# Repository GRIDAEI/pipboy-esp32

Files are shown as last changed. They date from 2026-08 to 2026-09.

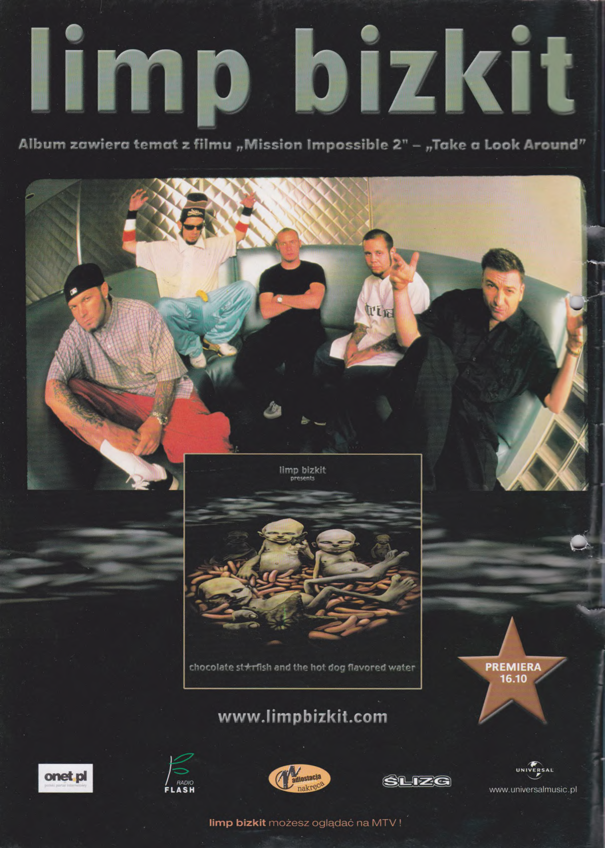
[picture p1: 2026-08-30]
FABRYKA-IMG-DO-ESP32/Klan Nr 15 (2000)_0002.png

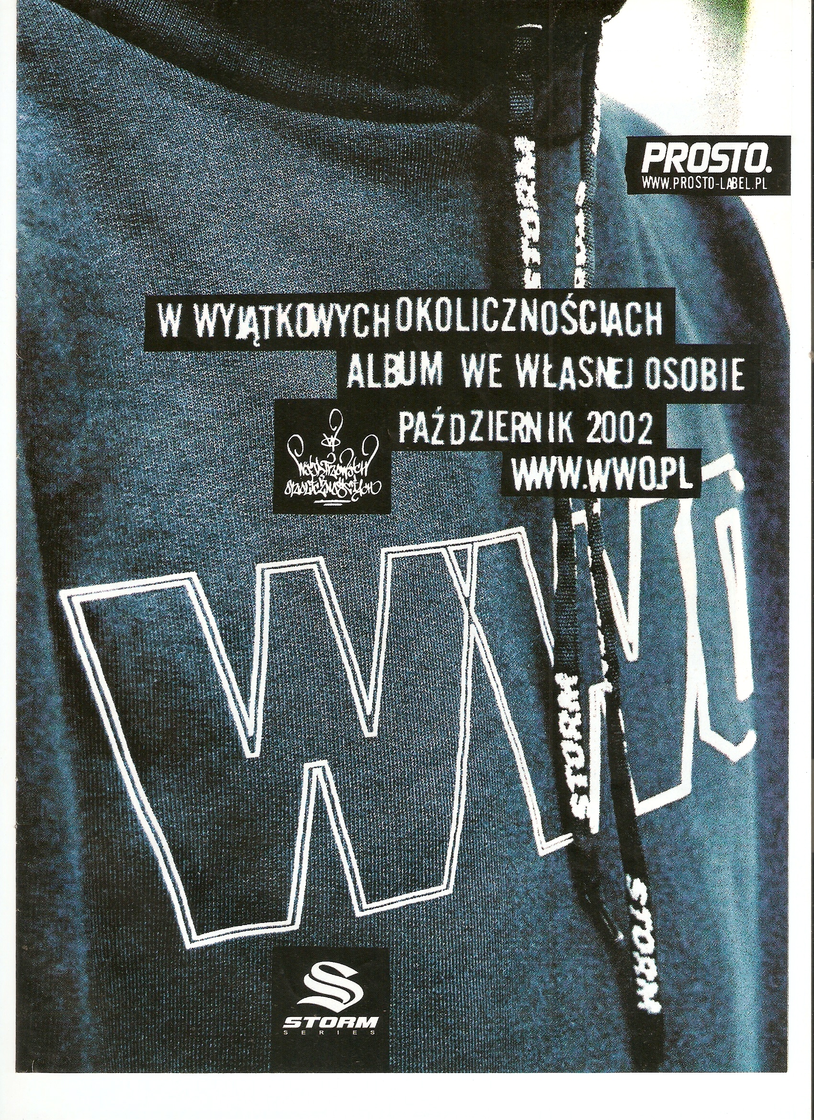
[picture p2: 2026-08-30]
FABRYKA-IMG-DO-ESP32/43xKLANxNr27x2002.jpg

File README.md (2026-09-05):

# Pip-Boy 3000 - ESP32-S3 Replica OS ☢️






Projekt ma na celu jak najdokładniejsze odtworzenie kultowego urządzenia z serii gier Fallout.
**Pip-Boy 3000**, znany głównie z _Fallout 3_ oraz _Fallout: New Vegas_, zyskuje tu nowe życie dzięki mikrokontrolerowi ESP32-S3. Projekt łączy oprogramowanie (UI/UX) z fizycznym sprzętem, tworząc realistyczny rekwizyt.

## Funkcje

- **Płynny Interfejs i Animacje**: Wykorzystanie biblioteki [LovyanGFX](https://github.com/lovyan03/LovyanGFX) zapewnia wysoką wydajność renderowania na ekranie.
- **System Audio I2S**: Autentyczne efekty dźwiękowe interfejsu (kliknięcia, przejścia w menu) odtwarzane przez `ESP8266Audio` i miksowane w czasie rzeczywistym.
- **Pełna Nawigacja**: Enkoder obrotowy, przełącznik obrotowy oraz fizyczne przyciski idealnie zmapowane, co pozwala na nawigację po zakładkach Statystyk, Ekwipunku i Danych, dokładnie tak jak w grze.
- **Ładowanie Obrazów do PSRAM**: Wysokiej rozdzielczości sprite'y (mapy, przedmioty) ładowane dynamicznie do 8MB pamięci PSRAM w celu oszczędzania pamięci RAM.
- **Zegar Czasu Rzeczywistego (RTC)**: Zegar systemowy z możliwością dostosowania i zapisem w pamięci NVS, odporny na restarty.
- **Motywy Kolorystyczne**: Obsługa różnych kolorów interfejsu (Klasyczny Zielony, Bursztynowy, Quantum Blue).
- **Oszczędzanie Energii**: Inteligentne wykrywanie bezczynności obniża taktowanie procesora do 80MHz, by oszczędzać baterię podczas długich wędrówek po Pustkowiach.

## Gotowe Płytki PCB

W projekcie zawarto pliki produkcyjne dla autorskich płytek drukowanych (PCB). Dostępne są **2 wersje** płytki, z czego **najnowsza rewizja v3.0 jest wysoce zalecana** ze względu na znaczne poprawki stabilności układu.

## Dokumentacja Projektu

Szczegółowe informacje techniczne oraz instrukcje zostały wydzielone do osobnych plików, aby ułatwić nawigację po repozytorium:

- **[Sprzęt i Elektronika (Hardware)](docs/HARDWARE.md)** – schemat układu, kompletna lista komponentów (BOM), tabela podłączeń pinów oraz informacje o zastosowanych modułach (wibracje, DAC).
- **[Architektura Oprogramowania (Software)](docs/SOFTWARE.md)** – objaśnienie działania interfejsu wizualnego (LovyanGFX), buforowanie tekstur w PSRAM, obsługa przerwań enkodera oraz zarządzanie dźwiękiem z LittleFS.
- **[Instrukcja Budowy (Build Guide)](docs/BUILD_GUIDE.md)** – przewodnik krok po kroku, jak skompilować projekt, skonfigurować środowisko PlatformIO i wgrać wymagany obraz pamięci Flash.

## 📁 Struktura Projektu

- `/src/screens/` - Logika odpowiedzialna za poszczególne zakładki interfejsu (Status, S.P.E.C.I.A.L, Ekwipunek, Mapy).
- `/src/modules/` - Sterowniki modułów takich jak Audio (I2S), Enkoder i obsługa karty SD.
- `/src/imgs/` - Tekstury, sprite'y i tablice z grafikami przygotowanymi do użycia.
- `/docs/` - Rozszerzona dokumentacja techniczna projektu.
- `main.cpp` - Główna pętla programu, sekwencja startowa (Boot OS) i dystrybucja wejść.

## Licencja

To jest projekt fanowski. _Pip-Boy_, _Vault Boy_ oraz _Fallout_ są zarejestrowanymi znakami towarowymi Bethesda Softworks LLC. Projekt został stworzony wyłącznie w celach edukacyjnych oraz hobbystycznych (cosplay).

---

_"Prepared for the Future"_ -- Vault-Tec Corporation

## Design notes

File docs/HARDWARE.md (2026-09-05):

# Sprzęt i Elektronika (Hardware)

Ten dokument opisuje warstwę sprzętową projektu Pip-Boy 3000, w tym użyte komponenty, zasilanie oraz peryferia.

## Schemat i Główne Moduły

Projekt opiera się na mikrokontrolerze **ESP32-S3**, który zarządza wyświetlaczem SPI, dźwiękiem I2S oraz czytnikiem kart pamięci, a także zbiera sygnały wejściowe od użytkownika.

### 1. Mikrokontroler

Zastosowano płytkę ewaluacyjną **ESP32-S3-DEVKITC-1-N16R8**.

- **Dlaczego ta wersja?** Układ ESP32-S3 jest wyposażony w dodatkową pamięć **8MB PSRAM (Octal SPI)**, co jest absolutnie kluczowe do buforowania dużych tekstur o wysokiej rozdzielczości (takich jak mapy czy animacje Vault Boya) bez zapychania standardowej pamięci RAM (której jest tylko 512KB).

### 2. Wyświetlacz TFT

Ekran komunikuje się z mikrokontrolerem po szybkiej magistrali SPI (piny `TFT_SCK`, `TFT_SDI`, `TFT_DC`, `TFT_CS`, `TFT_RESET`).

### 3. System Audio

Dźwięk generowany jest w pełni cyfrowo z wykorzystaniem protokołu I2S.

- **DAC:** Zewnętrzny moduł przetwornika (np. MAX98357A).
- Sygnały I2S: Zegar kanałów (`LRCLK`), Zegar bitowy (`BCLK`), oraz linia danych (`DIN`).

### 4. Sprzężenie zwrotne (Haptyka)

Aby symulować działanie "prawdziwego" urządzenia, zastosowano 2 silniczki wibracyjne (`Vibr1`, `Vibr2`).

- Są one sterowane poprzez **N-kanałowe tranzystory MOSFET** (Q2, Q3) działające jako klucze.
- Dołożono diody Schottky'ego (D1, D2) podłączone zaporowo, które pełnią funkcję tzw. _flyback diode_ – chronią porty mikrokontrolera przed przepięciami (skokami napięcia) powstającymi przy wyłączaniu cewek silników.

### 5. Pamięć Masowa

Płyta uwzględnia zewnętrzny moduł karty **Micro SD**, który służy jako dodatkowy magazyn danych na ciężkie pliki multimedialne.

---

## 🖨️ Projekty Płytek Drukowanych (PCB)

W głównym drzewie repozytorium znajdziesz gotowe projekty płytek drukowanych, które pozwalają złożyć system w profesjonalny, kompaktowy sposób bez plątaniny kabli (co ułatwia montaż w obudowie Pip-Boya).

Obecnie udostępniamy dwie wersje projektu PCB:

- **Wersja starsza**: Pierwotna koncepcja układu.
- **Wersja v3.0 (ZALECANA)**: Najnowsza rewizja płytki. Posiada kluczowe poprawki dotyczące stabilności układu, lepsze oddzielenie sekcji zasilania od części logicznej oraz zoptymalizowane prowadzenie ścieżek układu audio I2S (niwelacja szumów). Zdecydowanie polecamy produkcję i lutowanie **wersji v3.0**.

---

## 📋 Lista Komponentów (BOM)

Poniżej znajduje się zestawienie części potrzebnych do zbudowania elektroniki.

| Komponent | Model / Specyfikacja | Rola w systemie | Gdzie kupić (Link) |
| :--- | :--- | :--- | :--- |
| **Mikrokontroler** | ESP32-S3-DEVKITC-1-N16R8 | "Mózg" operacji, renderowanie UI, obsługa PSRAM | [Link](https://kamami.pl/esp32/1197037-esp32-s3-microcontroller-2-4ghz-wi-fi-development-board-240mhz-dual-core-processor-esp32-s3-wroom-5906623499045.html) |
| **Wyświetlacz** | [TFT SPI 4.0' ST7796] | Prezentacja interfejsu tft | [Link](https://pl.aliexpress.com/item/1005005787550807.html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) |
| **Przetwornik Audio** | MAX98357A | Odtwarzanie kliknięć i dźwięków UI po I2S | [Link](https://www.gotronik.pl/modul-wzmacniacza-audio-i2s-3w-klasa-d-dacmax98357-p-13866.html) |
| **Głośnik** | Głośnik 1W 8Ohm | Emisja dźwięku | [Link](https://botland.com.pl/glosniki-analogowe/26596-glosnik-1w-8ohm-30mm-sparkfun-com-27247-5904422387907.html) |
| **Enkoder obrotowy** | EC10E1220503 | Nawigacja góra/dół | [Link](https://www.tme.eu/pl/details/ec10e1220503/enkodery-inkrementalne/alps/) |
| **Przyciski funkcyjne** | [Uzupełnij np. Tact Switch 12x12mm]  | Zmiana zakładek (Stats, Items, Data) | [Uzupełnij] |
| **Silniki Wibracyjne** | [Uzupełnij np. płaskie silniki coin] | Haptyczne wibracje zwrotne | [Uzupełnij](Link) |
| **Tranzystory MOSFET** | [Uzupełnij np. 2N7002, logic-level]  | Włączanie zasilania silniczków (3.3V) z GPIO ESP32 | [Uzupełnij] |
| **Diody Zabezpieczające** | SS24 | Zabezpieczenie przed przepięciami z silników (flyback) | [Uzupełnij] |
| **Rezystory** | [Uzupełnij, np. 10kOhm pull-down] | Stabilizacja stanów na bramkach MOSFETów i SPI | [Uzupełnij] |
|  |

## 🔌 Tabela Połączeń (Pinout)

_Zostawiam to miejsce na szczegółową rozpiskę pinów. Ułatwia to testowanie na płytce stykowej._

| ESP32-S3 Pin | Komponent docelowy | Opis Sygnału |
| :--- | :--- | :--- |
| [Uzupełnij np. GPIO15] | `TFT_CS` | SPI Chip Select dla ekranu |
| ... | ... | ... |

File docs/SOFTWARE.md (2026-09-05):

# 💻 Architektura Oprogramowania (Software)

Projekt jest pisany w **C++** i kompilowany przy użyciu środowiska **PlatformIO** w frameworku Arduino dla ESP32.

Poniżej znajduje się omówienie kluczowych modułów programistycznych i decyzji architektonicznych.

## 🖼️ Interfejs Graficzny i Wyświetlacz (UI)

Zamiast standardowej i wolnej biblioteki TFT_eSPI, silnik GUI opiera się o bibliotekę **[LovyanGFX](https://github.com/lovyan03/LovyanGFX)**.

- **Wydajność:** LovyanGFX pozwala na asynchroniczne transfery DMA (Direct Memory Access) po magistrali SPI. Dzięki temu mikrokontroler nie jest zablokowany podczas przerysowywania pełnoekranowych klatek.
- **Double Buffering (Opcjonalnie):** W celu wyeliminowania zjawiska "migotania" (tearing/flickering) podczas odświeżania zakładek w interfejsie.

### Zarządzanie Pamięcią (PSRAM)

Zwykły ESP32 posiada zbyt mało pamięci RAM (ok. 520 KB), by pomieścić nieskompresowane mapy bitowe w 16-bitowym kolorze (np. 320x480).

- Rozwiązaniem jest wykorzystanie wariantu ESP32-S3 posiadającego **8MB zewnętrznej pamięci PSRAM**.
- Tekstury (jak grafiki Pip-Boya, mapy Pustkowi, ikony ekwipunku) zapisane są w pamięci flash. Podczas pracy programu, odpowiednie tekstury są wgrywane bezpośrednio na bieżąco (lub buforowane z wyprzedzeniem) do PSRAM przy użyciu `ps_malloc()`.
- Zapewnia to błyskawiczny dostęp do grafik podczas szybkiego przełączania między zakładkami.

## 🔊 System Audio (I2S)

Pip-Boy to nie tylko grafika, ale i kultowe dźwięki kliknięć i radiacji.

1.  Dźwięki (w formacie `.wav` lub `.mp3`) przechowywane są we wbudowanej pamięci Flash przy użyciu systemu plików **LittleFS** lub na zewnętrznej karcie pamięci Micro SD.
2.  Wykorzystywana jest biblioteka **ESP8266Audio**.
3.  Mikrokontroler strumieniuje dane dźwiękowe do zewnętrznego układu DAC poprzez sprzętową magistralę **I2S**. Użycie oddzielnego układu cyfrowo-analogowego minimalizuje zakłócenia i zniekształcenia dźwięku.
4.  Uruchomiono sprzętowe miksowanie kanałów, by w przyszłości nakładać efekty dźwiękowe UI (np. szum kliknięcia) na odtwarzane radio.

## 🎛️ Obsługa Wejść (Enkoder i Przyciski)

Do odczytu nawigacji wykorzystywany jest enkoder obrotowy i przyciski przednie (`FNTBTN`).

- **Przerwania (Interrupts):** Odczyt enkodera realizowany jest poprzez asynchroniczne przerwania sprzętowe (ISR), a nie poprzez ciągłe odpytywanie w pętli `loop()` (tzw. polling). Zapewnia to natychmiastową reakcję i to, że żaden "skok" obrotu nie zostanie zgubiony.
- **Debouncing:** Zaimplementowano programowy debouncing dla przycisków przednich oraz przełącznika pozycyjnego, by wyeliminować fałszywe podwójne wciśnięcia wywołane drganiem styków.

## ⚡ Struktura Główna

Kod źródłowy zorganizowany jest wokół głównych widoków:

- `/src/screens/` - Pliki definiujące rysowanie i logikę ekranów (Status, Inventory, Data, Map).
- `/src/modules/` - Klasy abstrakcyjne odpowiedzialne za podzespoły sprzętowe (Manager dźwięku, Manager wejść).

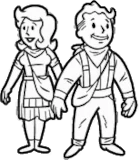
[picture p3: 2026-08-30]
FABRYKA-IMG-DO-ESP32/GoodspringsReputation.webp

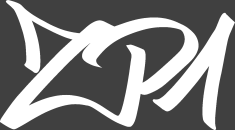
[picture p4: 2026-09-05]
FABRYKA-IMG-DO-ESP32/zp1.png

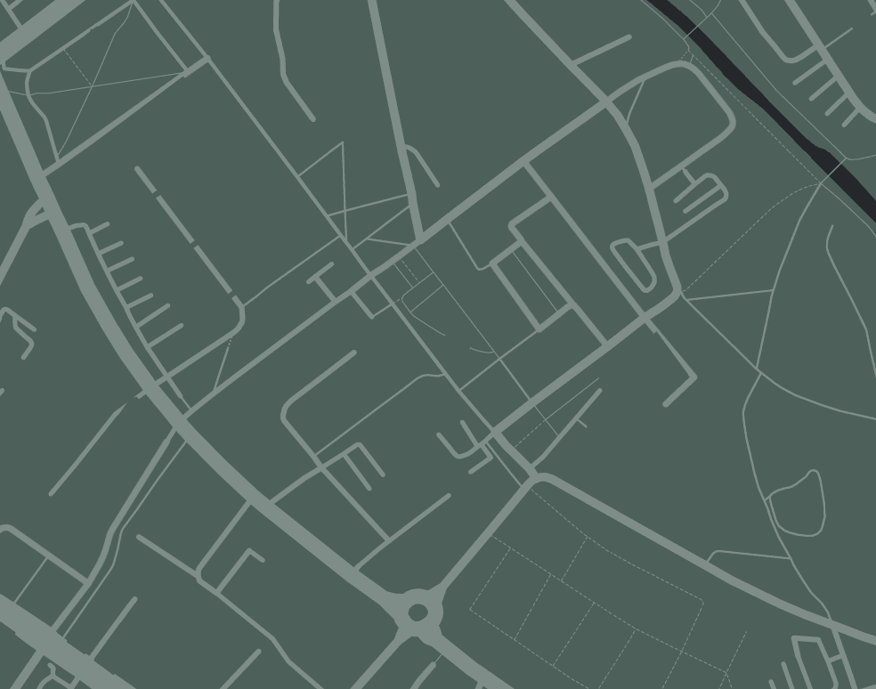
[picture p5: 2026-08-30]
FABRYKA-IMG-DO-ESP32/LocalMapSprite.png

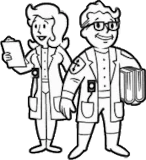
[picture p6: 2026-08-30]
FABRYKA-IMG-DO-ESP32/FollowersApocalypseReputation.webp

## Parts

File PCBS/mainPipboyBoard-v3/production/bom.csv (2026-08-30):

Designator | Footprint | Quantity | Value | LCSC Part #
C1 | C_Radial_D4.0mm_H5.0mm_P1.50mm | 1 | 100uF
C2 | 0805 | 1 | 100nF
C3 | C_Radial_D4.0mm_H5.0mm_P1.50mm | 1 | 470uF
C4 | 1206 | 1 | 100nF
C5 | 1206 | 1 | 10uf
D1, D2 | 1206 | 2 | D_Schottky
J1 | PinSocket_1x14_P2.54mm_Vertical | 1 | TFT
J11 | PinSocket_1x02_P2.54mm_Vertical | 1 | Vibr1
J12 | PinSocket_1x02_P2.54mm_Vertical | 1 | Vibr2
J13 | JST_ZH_B6B-ZR-SM4-TF_1x06-1MP_P1.50mm_Vertical | 1 | FNTBTNS
J2, J4 | PinSocket_1x01_P2.54mm_Vertical | 2 | Conn_01x01
J3 | 112JTDARR01 | 1 | Micro_SD_Card
J7 | PinSocket_1x03_P2.54mm_Vertical | 1 | PosSwitch
J8 | PinSocket_1x04_P2.54mm_Vertical | 1 | ROTENCODER
J9 | PinSocket_1x07_P2.54mm_Vertical | 1 | audio
Q2, Q3 | SOT-23 | 2 | AO3400A | C20917
R10, R4, R5, R6, R7, R8, R9 | 1206 | 7 | 10k
U1 | XCVR_ESP32-S3-DEVKITC-1-N8R2 | 1 | ESP32-S3-DEVKITC-1-N8R2

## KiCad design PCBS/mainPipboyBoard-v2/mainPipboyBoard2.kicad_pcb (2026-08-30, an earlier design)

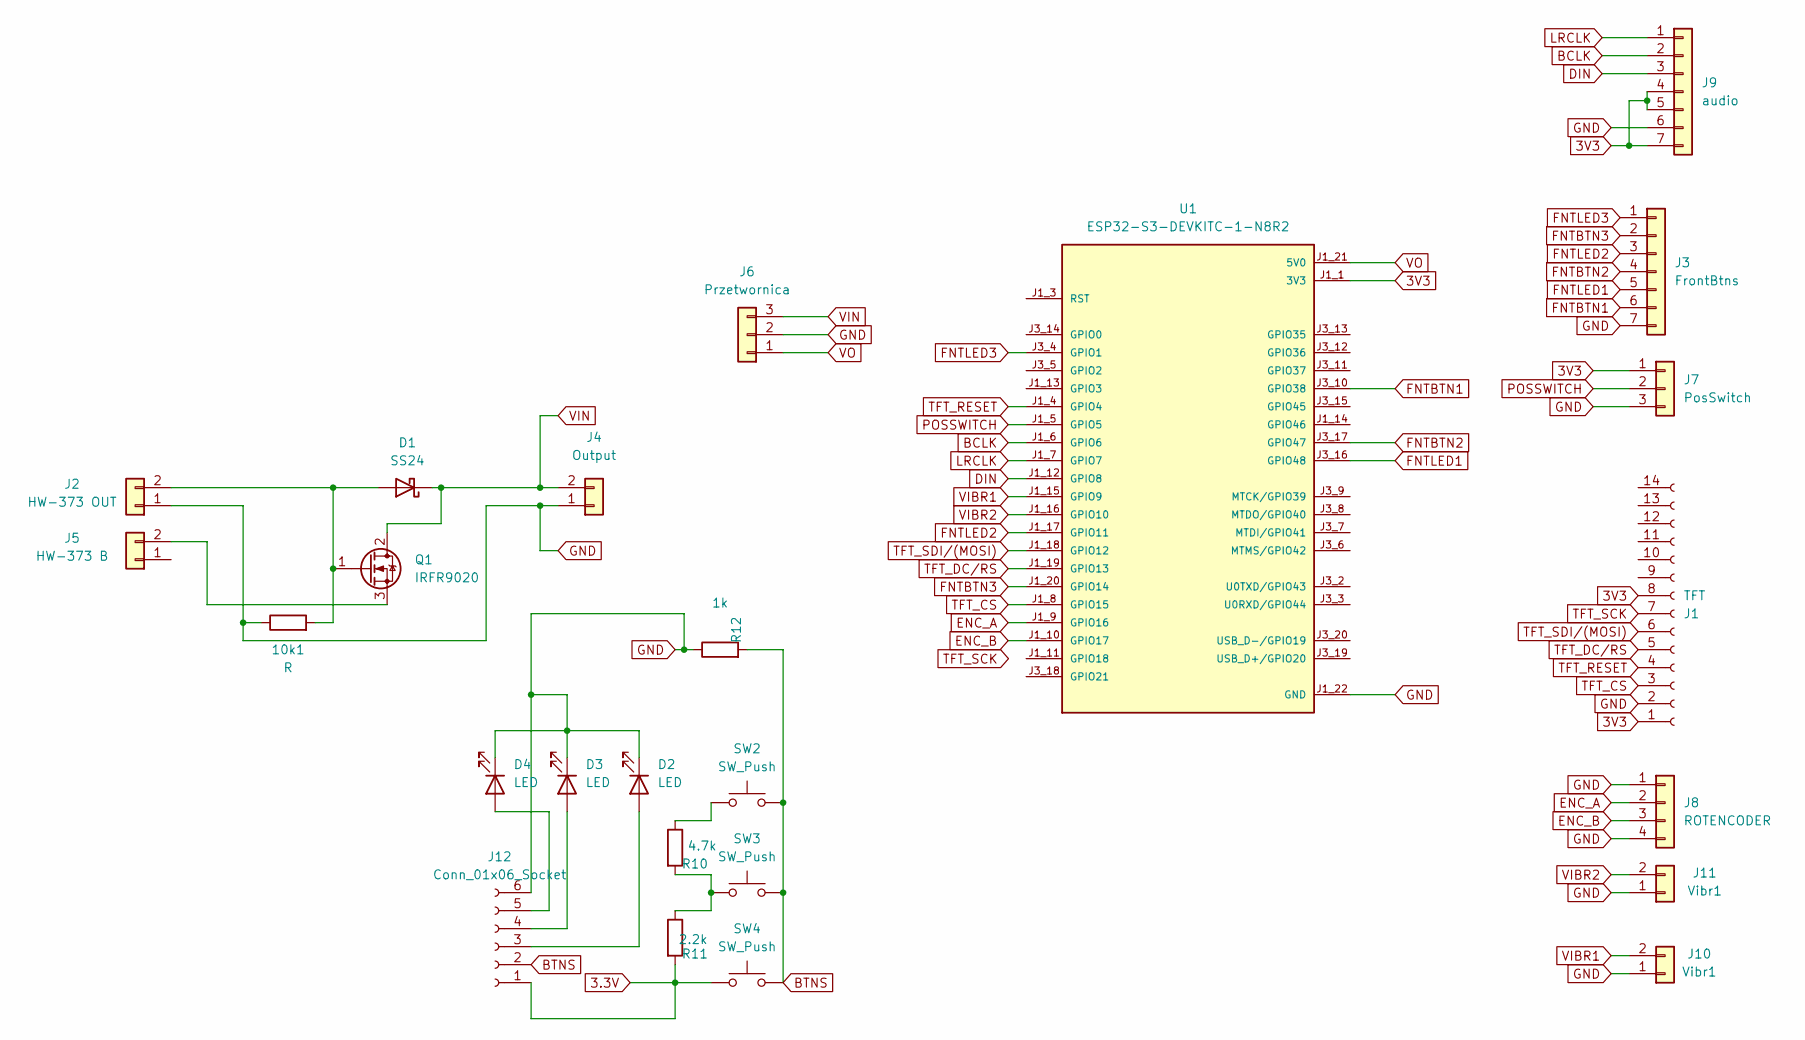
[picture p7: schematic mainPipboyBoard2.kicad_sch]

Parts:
10k1: R; R_1206_3216Metric_Pad1.30x1.75mm_HandSolder
D1: SS24; D_SMA
D2, D3, D4: LED; LED_1206_3216Metric_Pad1.42x1.75mm_HandSolder
J1: TFT; PinSocket_1x14_P2.54mm_Vertical
J2: HW-373 OUT; PinSocket_1x02_P2.54mm_Vertical
J3: FrontBtns; PinSocket_1x07_P2.54mm_Vertical
J4: Output; PinSocket_1x02_P2.54mm_Vertical
J5: HW-373 B; PinSocket_1x02_P2.54mm_Vertical
J6: Przetwornica; PinSocket_1x03_P2.54mm_Vertical
J7: PosSwitch; PinSocket_1x03_P2.54mm_Vertical
J8: ROTENCODER; PinSocket_1x04_P2.54mm_Vertical
J9: audio; PinSocket_1x07_P2.54mm_Vertical
J10, J11: Vibr1; PinSocket_1x02_P2.54mm_Vertical
J12: Conn_01x06_Socket; PinHeader_1x06_P2.54mm_Vertical_SMD_Pin1Right
Q1: IRFR9020; TO-252-2
R10: 4.7k; L_1206_3216Metric_Pad1.22x1.90mm_HandSolder
R11: 2.2k; L_1206_3216Metric_Pad1.22x1.90mm_HandSolder
R12: 1k; L_1206_3216Metric_Pad1.22x1.90mm_HandSolder
SW2, SW3, SW4: SW_Push; PTS810SJM250SMTRLFS
U1: ESP32-S3-DEVKITC-1-N8R2; XCVR_ESP32-S3-DEVKITC-1-N8R2; PARTREV V1

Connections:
3.3V: J12.1, R11.2, SW4.1
3V3: J1.1, J1.8, J7.1, J9.4, J9.5, J9.7, U1.J1_1 (3V3), U1.J1_2 (3V3)
BCLK: J9.2, U1.J1_6 (GPIO6)
BTNS: J12.2, R12.2, SW2.2, SW3.2, SW4.2
DIN: J9.3, U1.J1_12 (GPIO8)
ENC_A: J8.2, U1.J1_9 (GPIO16)
ENC_B: J8.3, U1.J1_10 (GPIO17)
FNTBTN1: J3.6, U1.J3_10 (GPIO38)
FNTBTN2: J3.4, U1.J3_17 (GPIO47)
FNTBTN3: J3.2, U1.J1_20 (GPIO14)
FNTLED1: J3.5, U1.J3_16 (GPIO48)
FNTLED2: J3.3, U1.J1_17 (GPIO11)
FNTLED3: J3.1, U1.J3_4 (GPIO1)
GND: 10k1.1, D2.1 (K), D3.1 (K), D4.1 (K), J1.2, J2.1, J3.7, J4.1, J6.2, J7.3, J8.1, J8.4, J9.6, J10.1, J11.1, J12.6, R12.1, U1.J1_22 (GND), U1.J3_1 (GND), U1.J3_21 (GND), U1.J3_22 (GND)
LRCLK: J9.1, U1.J1_7 (GPIO7)
unnamed: 10k1.2, D1.2 (A), J2.2, Q1.1 (G)
unnamed: D2.2 (A), J12.3
unnamed: D3.2 (A), J12.4
unnamed: D4.2 (A), J12.5
unnamed: J5.2 (Pin_2_2), Q1.3 (S)
unnamed: R10.1, SW2.1
unnamed: R10.2, R11.1, SW3.1
POSSWITCH: J7.2, U1.J1_5 (GPIO5)
TFT_CS: J1.3, U1.J1_8 (GPIO15)
TFT_DC/RS: J1.5, U1.J1_19 (GPIO13)
TFT_RESET: J1.4, U1.J1_4 (GPIO4)
TFT_SCK: J1.7
TFT_SDI/(MOSI): J1.6, U1.J1_18 (GPIO12)
VIBR1: J10.2, U1.J1_15 (GPIO9)
VIBR2: J11.2, U1.J1_16 (GPIO10)
VIN: D1.1 (K), J4.2, J6.3, Q1.2 (D)
VO: J6.1, U1.J1_21 (5V0)

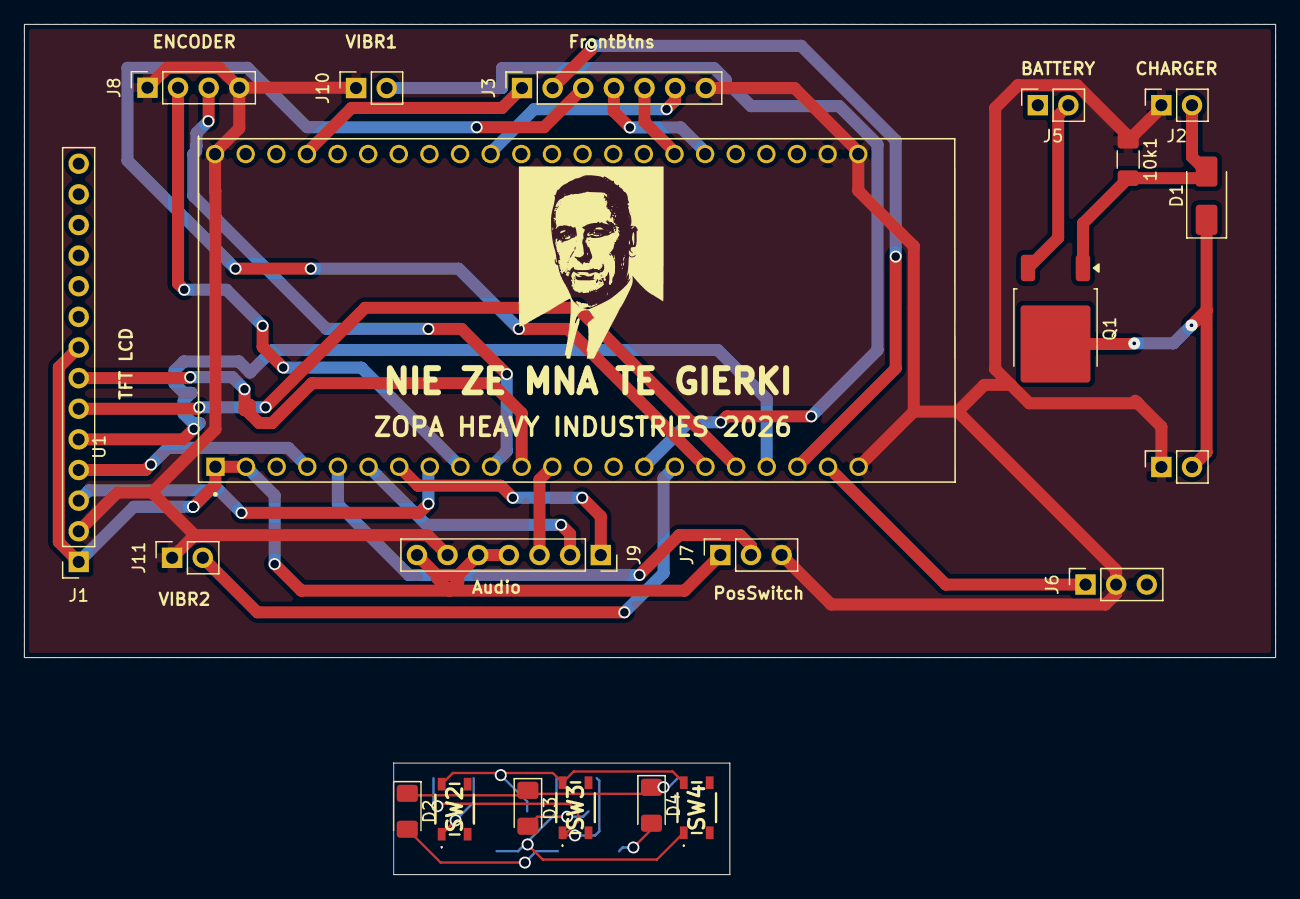
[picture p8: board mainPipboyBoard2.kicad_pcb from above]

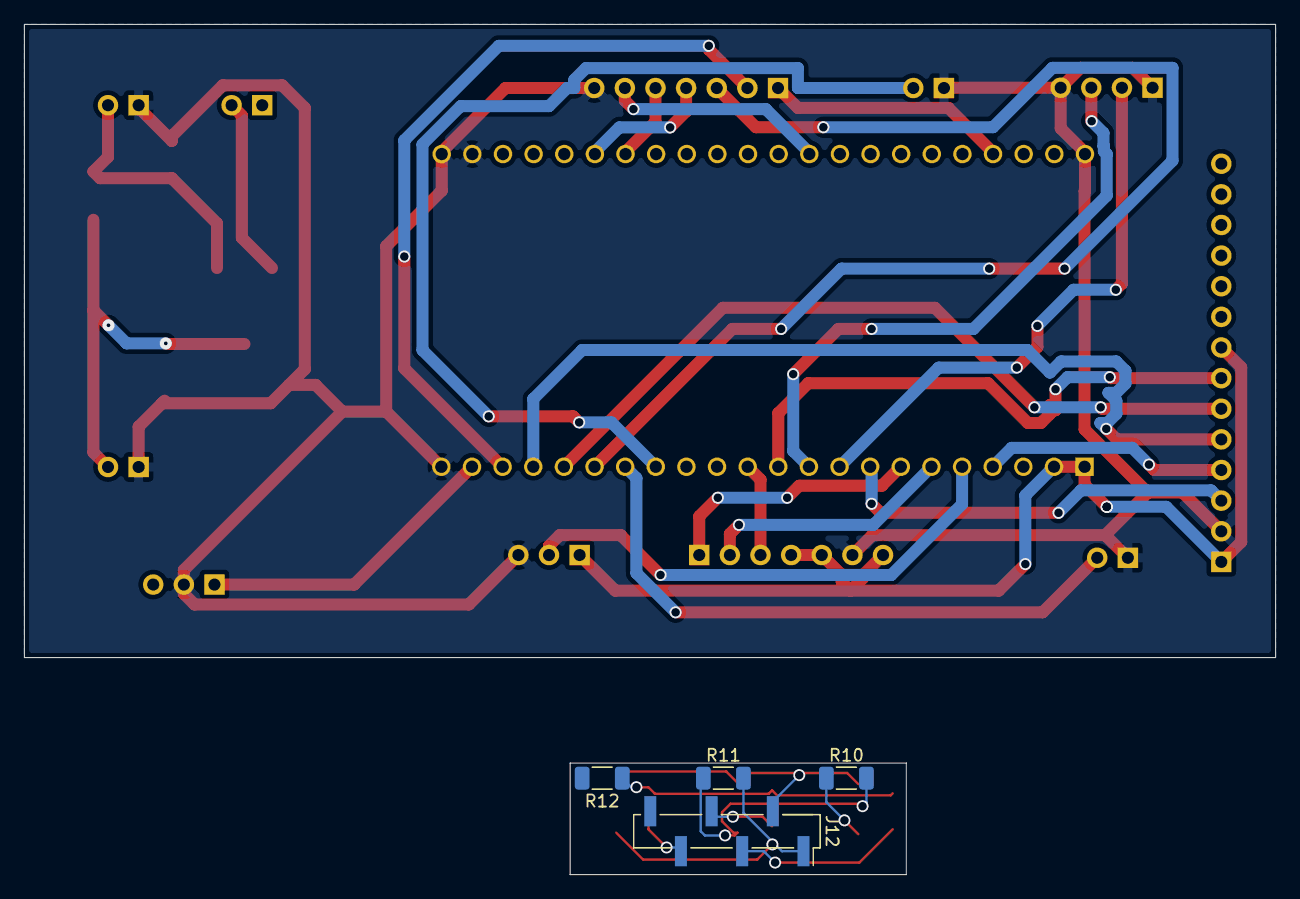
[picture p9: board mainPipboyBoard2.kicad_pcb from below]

Board: 2 copper layers, 103.8 x 70.5 mm, 25 parts (4 on the bottom side), 31 nets.

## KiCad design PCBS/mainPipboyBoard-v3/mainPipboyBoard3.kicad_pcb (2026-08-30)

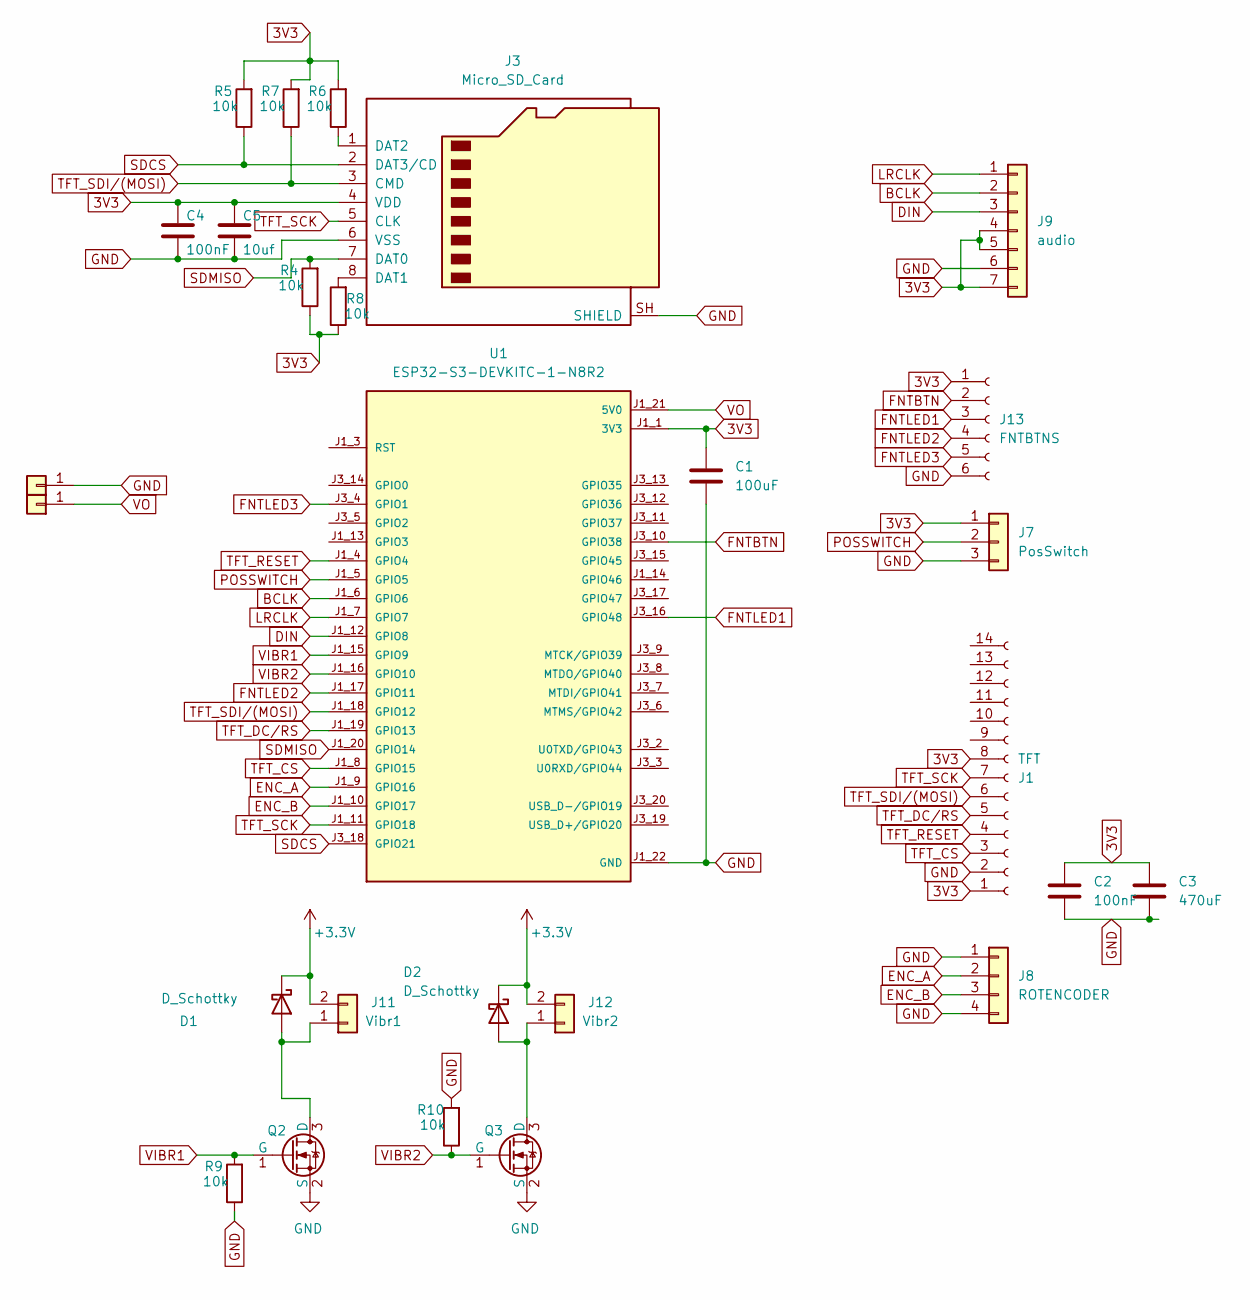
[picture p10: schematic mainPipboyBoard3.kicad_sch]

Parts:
C1: 100uF; C_Radial_D4.0mm_H5.0mm_P1.50mm
C2: 100nF; C_0805_2012Metric_Pad1.18x1.45mm_HandSolder
C3: 470uF; C_Radial_D4.0mm_H5.0mm_P1.50mm
C4: 100nF; L_1206_3216Metric_Pad1.22x1.90mm_HandSolder
C5: 10uf; L_1206_3216Metric_Pad1.22x1.90mm_HandSolder
D1, D2: D_Schottky; D_1206_3216Metric_Pad1.42x1.75mm_HandSolder
J1: TFT; PinSocket_1x14_P2.54mm_Vertical
J2, J4: Conn_01x01; PinSocket_1x01_P2.54mm_Vertical
J3: Micro_SD_Card; 112JTDARR01
J7: PosSwitch; PinSocket_1x03_P2.54mm_Vertical
J8: ROTENCODER; PinSocket_1x04_P2.54mm_Vertical
J9: audio; PinSocket_1x07_P2.54mm_Vertical
J11: Vibr1; PinSocket_1x02_P2.54mm_Vertical
J12: Vibr2; PinSocket_1x02_P2.54mm_Vertical
J13: FNTBTNS; JST_ZH_B6B-ZR-SM4-TF_1x06-1MP_P1.50mm_Vertical
Q2, Q3: AO3400A; SOT-23; Part AO3400A; LCSC Part Number C20917
R4, R5, R6, R7, R8, R9, R10: 10k; L_1206_3216Metric_Pad1.22x1.90mm_HandSolder
U1: ESP32-S3-DEVKITC-1-N8R2; XCVR_ESP32-S3-DEVKITC-1-N8R2; PARTREV V1

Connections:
3V3: C1.2, C2.2, C3.2, C4.1, C5.1, J1.1, J1.8, J3.4 (VDD), J7.1, J9.4, J9.5, J9.7, J13.1, R4.1, R5.2, R6.2, R7.2, R8.1, U1.J1_1 (3V3), U1.J1_2 (3V3)
+3.3V: D1.1 (K), D2.1 (K), J11.2, J12.2
BCLK: J9.2, U1.J1_6 (GPIO6)
DIN: J9.3, U1.J1_12 (GPIO8)
ENC_A: J8.2, U1.J1_9 (GPIO16)
ENC_B: J8.3, U1.J1_10 (GPIO17)
FNTBTN: J13.2, U1.J3_10 (GPIO38)
FNTLED1: J13.3, U1.J3_16 (GPIO48)
FNTLED2: J13.4, U1.J1_17 (GPIO11)
FNTLED3: J13.5, U1.J3_4 (GPIO1)
GND: C1.1, C2.1, C3.1, C4.2, C5.2, J1.2, J3.6 (VSS), J3.SH (SHIELD), J4.1 (Pin_1_1), J7.3, J8.1, J8.4, J9.6, J13.6, Q2.2 (S), Q3.2 (S), R9.1, R10.2, U1.J1_22 (GND), U1.J3_1 (GND), U1.J3_21 (GND), U1.J3_22 (GND)
LRCLK: J9.1, U1.J1_7 (GPIO7)
unnamed: D1.2 (A), J11.1, Q2.3 (D)
unnamed: D2.2 (A), J12.1, Q3.3 (D)
unnamed: J3.8 (DAT1), R8.2
unnamed: J3.1 (DAT2), R6.1
POSSWITCH: J7.2, U1.J1_5 (GPIO5)
SDCS: J3.2 (DAT3/CD), R5.1, U1.J3_18 (GPIO21)
SDMISO: J3.7 (DAT0), R4.2, U1.J1_20 (GPIO14)
TFT_CS: J1.3, U1.J1_8 (GPIO15)
TFT_DC/RS: J1.5, U1.J1_19 (GPIO13)
TFT_RESET: J1.4, U1.J1_4 (GPIO4)
TFT_SCK: J1.7, J3.5 (CLK), U1.J1_11 (GPIO18)
TFT_SDI/(MOSI): J1.6, J3.3 (CMD), R7.1, U1.J1_18 (GPIO12)
VIBR1: Q2.1 (G), R9.2, U1.J1_15 (GPIO9)
VIBR2: Q3.1 (G), R10.1, U1.J1_16 (GPIO10)
VO: J2.1 (Pin_1_1), U1.J1_21 (5V0)

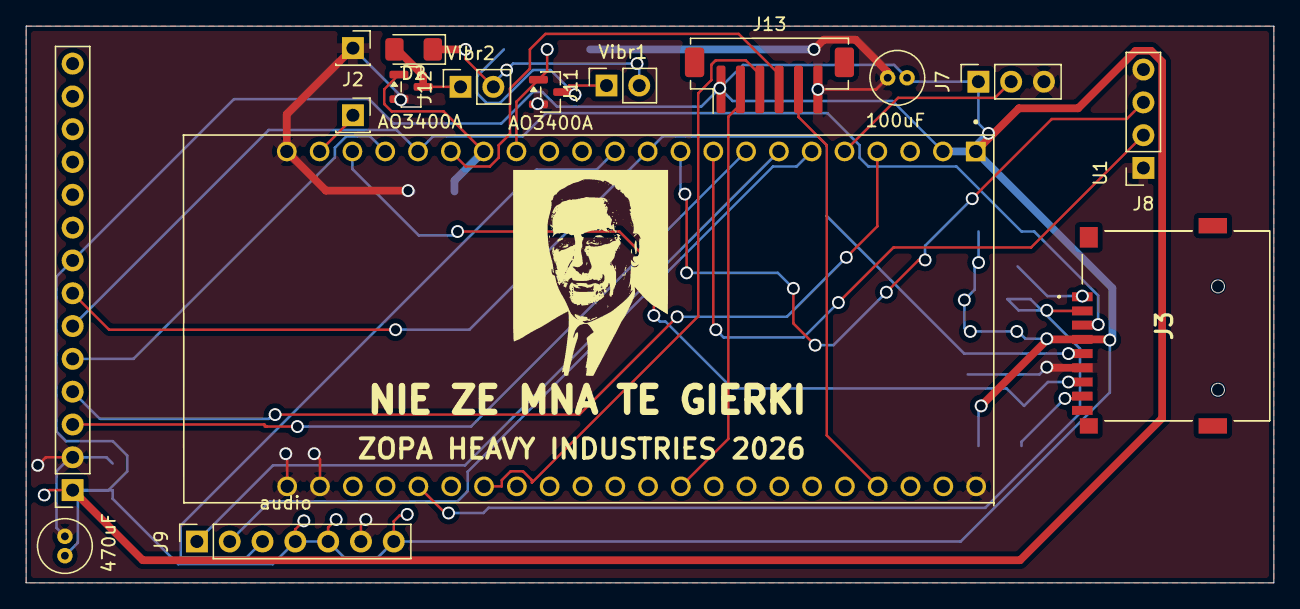
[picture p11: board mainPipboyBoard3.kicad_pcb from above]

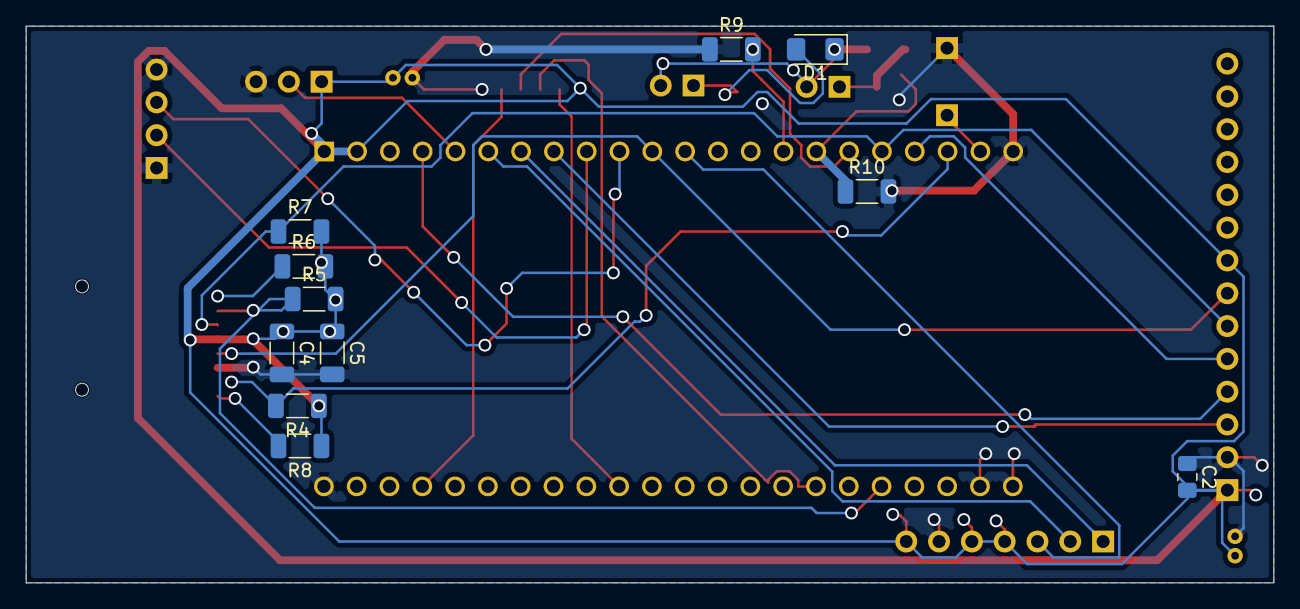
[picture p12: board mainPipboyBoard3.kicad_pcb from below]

Board: 2 copper layers, 96.6 x 43.1 mm, 27 parts (11 on the bottom side), 27 nets.

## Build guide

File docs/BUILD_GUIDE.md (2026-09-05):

# 🚀 Instrukcja Budowy i Uruchomienia (Build Guide)

Ten projekt zarządzany jest w pełni poprzez środowisko **PlatformIO**, co ułatwia zarządzanie bibliotekami i flagami dla frameworka ESP-IDF / Arduino.

## 1. Wymagania wstępne

- Pobierz i zainstaluj edytor **Visual Studio Code (VS Code)**.
- Zainstaluj rozszerzenie **PlatformIO IDE** w VS Code.
- Przygotuj płytkę ESP32-S3 oraz odpowiedni kabel USB ze wsparciem przesyłu danych.

## 2. Klonowanie i konfiguracja

1. Sklonuj repozytorium:
   ```bash
   git clone https://github.com/TwojaNazwaUzytkownika/PipBoy-ESP32.git
   ```
2. Otwórz pobrany folder w VS Code (PlatformIO powinno automatycznie rozpoznać projekt i rozpocząć pobieranie paczek).
3. (Opcjonalnie) Dostosuj środowisko w pliku `platformio.ini`, upewnij się, że port COM jest prawidłowo wykrywany.

## 3. Wgrywanie systemu plików (PAMIĘTAJ O TYM!)

Projekt wymaga plików multimedialnych (dźwięki, grafiki statyczne, czcionki), które umieszczone są w folderze `data/`. Należy je wgrać na osobną partycję **LittleFS** we Flashu mikrokontrolera.

- W VS Code rozwiń menu **PlatformIO** po lewej stronie (ikona mrówki).
- Wybierz swój profil (np. `esp32-s3-devkitc-1`).
- Rozwiń zakładkę **Platform**.
- Kliknij zadanie **Build Filesystem Image**.
- Następnie kliknij **Upload Filesystem Image**.
  _(Uwaga: w zależności od Twojego układu, wgrywanie obrazu przez USB może wymagać wciśnięcia przycisku BOOT na płytce)._

## 4. Wgrywanie Kodu Głównego

Gdy system plików jest już na mikrokontrolerze, można wgrać kod aplikacji:

1. Kliknij na ikonę strzałki (`Upload`) w dolnym pasku narzędzi VS Code PlatformIO.
2. Po pomyślnym kompilowaniu i wysłaniu, podgląd można uruchomić klikając w ikonę wtyczki (`Serial Monitor`), by śledzić komunikaty logowania i błędów w sekwencji startowej Boot OS.

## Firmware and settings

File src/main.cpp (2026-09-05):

#include <Arduino.h>
#include <LovyanGFX.hpp>
#include "screens/screen.h"


#include "display.h"
#include "config.h"
#include <LittleFS.h>
#include "imgs/pip.h"
#include "modules/audio.h"
#include "modules/rtc.h"
#include "modules/rotSwitch.h"


#include "soc/soc.h"
#include "soc/rtc_cntl_reg.h"

const int FNTBTN1 = 38;
const int FNTBTN2 = 47;
const int FNTBTN3 = 14;

const int FNTLED1 = 48;
const int FNTLED2 = 11;
const int FNTLED3 = 1;


bool fntBtn1Prev = HIGH;
bool fntBtn2Prev = HIGH;
bool fntBtn3Prev = HIGH;


int upbtn =46;
bool upclk = false;
bool upPrev = HIGH;
int downbtn =3;
bool downclk = false;
bool downPrev = HIGH;

int vibr_pin = 10;
int vibr_ms = 80;

int rtc_sda = 8;
int rtc_scl = 9;

// int selectBtn = 41;
bool selectPrev = HIGH;
unsigned long vibroEnd = 0;
uint32_t COLOR_BG = F3_BG;
uint32_t COLOR_GREEN = F3_GREEN;
ESP32Encoder encoder;

void vibrate(int ms = vibr_ms) {
    digitalWrite(vibr_pin, HIGH);
    vibroEnd = millis() + ms;
}

void handleVibro() {
    if (vibroEnd > 0 && millis() >= vibroEnd) {
        digitalWrite(vibr_pin, LOW);
        vibroEnd = 0;
    }
}
void updateFrontLeds(int active_section) {
    digitalWrite(FNTLED1, active_section == 0 ? HIGH : LOW);
    digitalWrite(FNTLED2, active_section == 1 ? HIGH : LOW);
    digitalWrite(FNTLED3, active_section == 2 ? HIGH : LOW);
}
// Zmienna trzymająca aktualnie przetwarzaną pozycję enkodera
extern int32_t currentRenderEncoderCount; 

// Zwraca true, jeśli użytkownik ruszył enkoderem podczas rysowania

RotSwitch rSwitch(5);
void set_green(){
    COLOR_BG = F3_BG;
    COLOR_GREEN = F3_GREEN;
}
void set_nv(){
    COLOR_BG = NV_BG;
    COLOR_GREEN = NV_AMBER;
}
void setup() {
  delay(500); 
  
  Serial.begin(115200);
  delay(500);
  Serial.println("Startt!!!");
  
  set_green();
  init_all_stats();

  tft.init();               
  tft.setRotation(1);
  if (!LittleFS.begin()) {
    Serial.println("LittleFS mount failed!");
  } else {
     Serial.println("Wczytujemy obrazy");
    load_all_sprites(); 
  } 
  tft.fillScreen(COLOR_BG);
  initAudio();    
  
  auto waitWithAudio = [](unsigned long ms) {
      unsigned long start = millis();
      while (millis() - start < ms) {
          handleAudio();
          delay(1); 
      }
  };

  tft.setFont(&monofonto_rg13pt7b);
  tft.setTextColor(COLOR_GREEN, COLOR_BG);
  tft.setTextDatum(TL_DATUM);
  tft.setCursor(10, 10);
  
  tft.println("RobCo OS v8.1 Boot...");
  playSound("/deck_ui_bumper_end_02.wav");
  waitWithAudio(300);
  
  tft.println("Memory Check: 64K OK");
  waitWithAudio(300);
  
  for (int i = 0; i < 7; i++) {
      String line = "";
      line += "0x" + String(random(0x1000, 0xFFFF), HEX) + "  ";
      for (int j = 0; j < 24; j++) {
          line += (random(2) == 0) ? "0 " : "1 ";
      }
      playSound("/deck_ui_slider_up.wav");
      tft.println(line);
      waitWithAudio(120); 
  }
  
  waitWithAudio(400); 

  tft.fillScreen(COLOR_BG);
  
  tft.setFont(&monofonto_rg70pt7b);
  tft.setTextDatum(MC_DATUM);  
  tft.drawString("PIP-BOY", 240, 100);
  
  tft.setFont(&monofonto_rg13pt7b);
  tft.setTextSize(2.0); 
  tft.drawString("3000", 240, 180);
  
  tft.setTextSize(1.5);
  String welcome = "Witaj, ";
  welcome += objStatusScreen.getPlayerName();
  tft.drawString(welcome, 240, 240);
  playSound("/deck_ui_achievement_toast.wav");
  tft.setTextSize(1.0);
  tft.unloadFont();
  tft.setTextDatum(TL_DATUM); 
  
  unsigned long intro_start = millis(); 

    pinMode(FNTBTN1, INPUT_PULLUP);
    pinMode(FNTBTN2, INPUT_PULLUP);
    pinMode(FNTBTN3, INPUT_PULLUP);

    pinMode(FNTLED1, OUTPUT);
    pinMode(FNTLED2, OUTPUT);
    pinMode(FNTLED3, OUTPUT);
    updateFrontLeds(section_id);
  pinMode(upbtn, INPUT_PULLUP);
  pinMode(downbtn, INPUT_PULLUP);
  pinMode(vibr_pin, OUTPUT);
  digitalWrite(vibr_pin, LOW);


  ESP32Encoder::useInternalWeakPullResistors = puType::up;
  encoder.attachHalfQuad(16, 17);
  encoder.setCount(0);
  


  while (millis() - intro_start < 3000) {
      handleAudio();
      delay(10);
  }
  tft.fillScreen(COLOR_BG); // Zamazujemy napis PIP-BOY nowym tłem
  current_screen = &Status_Screen;
  Serial.println("Rysuje ekran");
  topbot();
  if (current_screen->drawFunction) {
      current_screen->drawFunction();
  } else {
      Serial.println("BLAD: drawFunction jest PUSTE! Brakuje przypisania.");
  }
            // 4. audio
  Serial.println("Done!");

}

void handleFrontButtons() {
    bool btn1Now = digitalRead(FNTBTN1);
    bool btn2Now = digitalRead(FNTBTN2);
    bool btn3Now = digitalRead(FNTBTN3);

    // Reakcja na kliknięcie przycisku 1 (Przejście do STATS)
    if (fntBtn1Prev == HIGH && btn1Now == LOW) {
        if (section_id != 0) { // Zmieniaj tylko jeśli to nowa sekcja
            change_section(0);
            updateFrontLeds(0);
            playSound("/switch_opt.wav");
        }
    }
    
    // Reakcja na kliknięcie przycisku 2 (Przejście do ITEMS)
    if (fntBtn2Prev == HIGH && btn2Now == LOW) {
        if (section_id != 1) {
            change_section(1);
            updateFrontLeds(1);
            playSound("/switch_opt.wav");
        }
    }

    // Reakcja na kliknięcie przycisku 3 (Przejście do DATA)
    if (fntBtn3Prev == HIGH && btn3Now == LOW) {
        if (section_id != 2) {
            change_section(2);
            updateFrontLeds(2);
            playSound("/switch_opt.wav");
        }
    }

    // Zapisz stan do kolejnej pętli
    fntBtn1Prev = btn1Now;
    fntBtn2Prev = btn2Now;
    fntBtn3Prev = btn3Now;
}

unsigned long last_input_time = 0;
bool is_screen_dimmed = false;
const unsigned long DIM_TIMEOUT = 15000; // 15 sekund bezczynności -> tryb oszczędzania

void loop() {
    static unsigned long lastPrint = 0;
if (millis() - lastPrint > 500) {
    lastPrint = millis();
}
  handleAudio();
  bool upNow = digitalRead(upbtn);
  bool downNow = digitalRead(downbtn);
  bool selectNow = HIGH;

    if (Serial.available() > 0) {
        char c = Serial.read();
        if      (c == 'w' || c == 'W') upNow = LOW;
        else if (c == 'd' || c == 'D') {set_screen(screen_id + 1);playSound("/deck_ui_side_menu_fly_in.wav");}
        else if (c == 'a' || c == 'A') {set_screen(screen_id - 1);playSound("/deck_ui_side_menu_fly_in.wav");}
        else if (c == 's' || c == 'S') downNow = LOW;
        else if (c == 'v' || c == 'V') selectNow = LOW;
        else if (c == 'l' || c == 'L'){ change_section(section_id + 1);playSound("/deck_ui_tab_transition_01.wav");}
        else if (c == 'k' || c == 'K'){ change_section(section_id - 1);playSound("/deck_ui_tab_transition_01.wav");}
    }
    int newPos = rSwitch.update();
    if (newPos != -1) {
        playSound("/deck_ui_side_menu_fly_in.wav");
        set_screen(newPos);
    }
    
  static int32_t lastEncoderCount = 0;               
  int32_t currentCount = (int32_t)encoder.getCount(); 

  if (upPrev == HIGH && downPrev == HIGH) {
      if (currentCount > lastEncoderCount) {
          downNow = LOW;       
          lastEncoderCount++;  
      } 
      else if (currentCount < lastEncoderCount) {
          upNow = LOW;         
          lastEncoderCount--;  
      }
  }

    currentRenderEncoderCount = lastEncoderCount;

    bool input_detected = false;
    if (upPrev == HIGH && upNow == LOW) input_detected = true;
    if (downPrev == HIGH && downNow == LOW) input_detected = true;
    if (selectPrev == HIGH && selectNow == LOW) input_detected = true;
    if (newPos != -1) input_detected = true;

    if (input_detected) {
        last_input_time = millis();
        if (is_screen_dimmed) {
            is_screen_dimmed = false;
            setCpuFrequencyMhz(240); 
            
            upNow = HIGH;
            downNow = HIGH;
            selectNow = HIGH;
        }
    }

    if (!is_screen_dimmed && (millis() - last_input_time > DIM_TIMEOUT)) {
        is_screen_dimmed = true;
        setCpuFrequencyMhz(80); 
    }
  if(upPrev == HIGH && upNow == LOW){
      current_up();
      playSound("/deck_ui_navigation.wav");
  }
  if(downPrev == HIGH && downNow == LOW){
      current_down();
      playSound("/deck_ui_navigation.wav");
  }
  if(selectPrev == HIGH && selectNow == LOW){
      press_current_select();
      playSound("/switch_opt.wav");
  }

  if (section_id == 0 && screen_id == 0) {
      objStatusScreen.update();
  }
  
  static int last_saved_minute = -1;
  time_t now;
  struct tm timeinfo;
  time(&now);
  localtime_r(&now, &timeinfo);
  
  if (timeinfo.tm_year > 100 && timeinfo.tm_min != last_saved_minute) {
      last_saved_minute = timeinfo.tm_min;
      
      Preferences prefs;
      prefs.begin("zegar", false);
      prefs.putULong("zapisany_czas", now);
      prefs.end();
  }
  
  upPrev = upNow;
  downPrev = downNow;
  selectPrev = selectNow;
  delay(5);
}

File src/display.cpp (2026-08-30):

#include "display.h"
#include "config.h"
#include <LittleFS.h>
LGFX tft;  // jedyna prawdziwa definicja obiektu

LGFX::LGFX(void) {
  { // Magistrala
    auto cfg = _bus_instance.config();
    cfg.spi_host = SPI2_HOST;
    cfg.spi_mode = 0;
    cfg.freq_write = 40000000;
    cfg.pin_sclk = 18;
    cfg.pin_mosi = 12;
    cfg.pin_miso = 19;
    cfg.pin_dc   = 13;
    cfg.dma_channel = SPI_DMA_CH_AUTO;
    _bus_instance.config(cfg);
    _panel_instance.setBus(&_bus_instance);
  }
  { // Panel
    auto cfg = _panel_instance.config();
    cfg.pin_cs  = 15;
    cfg.pin_rst = 4;
    cfg.panel_width  = 320;
    cfg.panel_height = 480;
    cfg.rgb_order = true;
    _panel_instance.config(cfg);
  }
  /* { 
    auto cfg = _light_instance.config();
    cfg.pin_bl = -1; 
    cfg.invert = false;
    cfg.freq   = 44100;           
    cfg.pwm_channel = 7;          
    _light_instance.config(cfg);
    _panel_instance.setLight(&_light_instance);
  } */
  setPanel(&_panel_instance);
}

void initDisplay() {
  tft.init();
  tft.setRotation(1);
  // Uruchom LittleFS
  LittleFS.begin();
  if (!LittleFS.begin()) {
    Serial.println("LittleFS mount failed!");
    return;
  }
  tft.fillScreen(COLOR_BG);
}
